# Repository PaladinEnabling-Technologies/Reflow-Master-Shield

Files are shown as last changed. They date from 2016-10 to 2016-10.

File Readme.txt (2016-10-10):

Readme
:
*******

1. Congratulations if you've purchased an Paladin Enabling Technologies solder reflow shield / controller, 
   if you decide to make it yourself, goodluck.

2. Before we can start reflowing your boards you will have to first load the EEPROM Population sketch onto the board,
   this is to move the default values into the EEPROM and to save you some time programming it in by hand.

3. If your not using an Arduino UNO but an Arduino Mega, then you will have to copy a replacement config file
   into your openGLCD library folder so that the shield will work.

4. The file is found in the "Master Config File - Same Pinout for all boards" folder and must be copied to the
   "C:\Program Files\Arduino\libraries\openGLCD" folder if this is your installation path of your Arduino IDE.

5. You can replace this file with the original master config file found in the "Master Config File - Original"
   folder if your not going to use the shield anymore and would like to use the default pinout for the Arduino Mega,

6. Next we can load the main Solder Reflow Oven Coding Sketch onto your board. There are two versions available. One for
   the UNO and one for the MEGA. 

7. Please note that the default values are for the toaster oven that we have used,
   you might have to adjust it for the oven your using as well as for the solder paste.

8. Please note that when you're in a submenu, you can navigate through it by pressing the ENT button.
   You can't escape so you must navigate through the menu. (You will notice that the "ESC" will disappear if you need to 
   navigate through a submenu)

9. Please read through the additional documentation in the sketches.

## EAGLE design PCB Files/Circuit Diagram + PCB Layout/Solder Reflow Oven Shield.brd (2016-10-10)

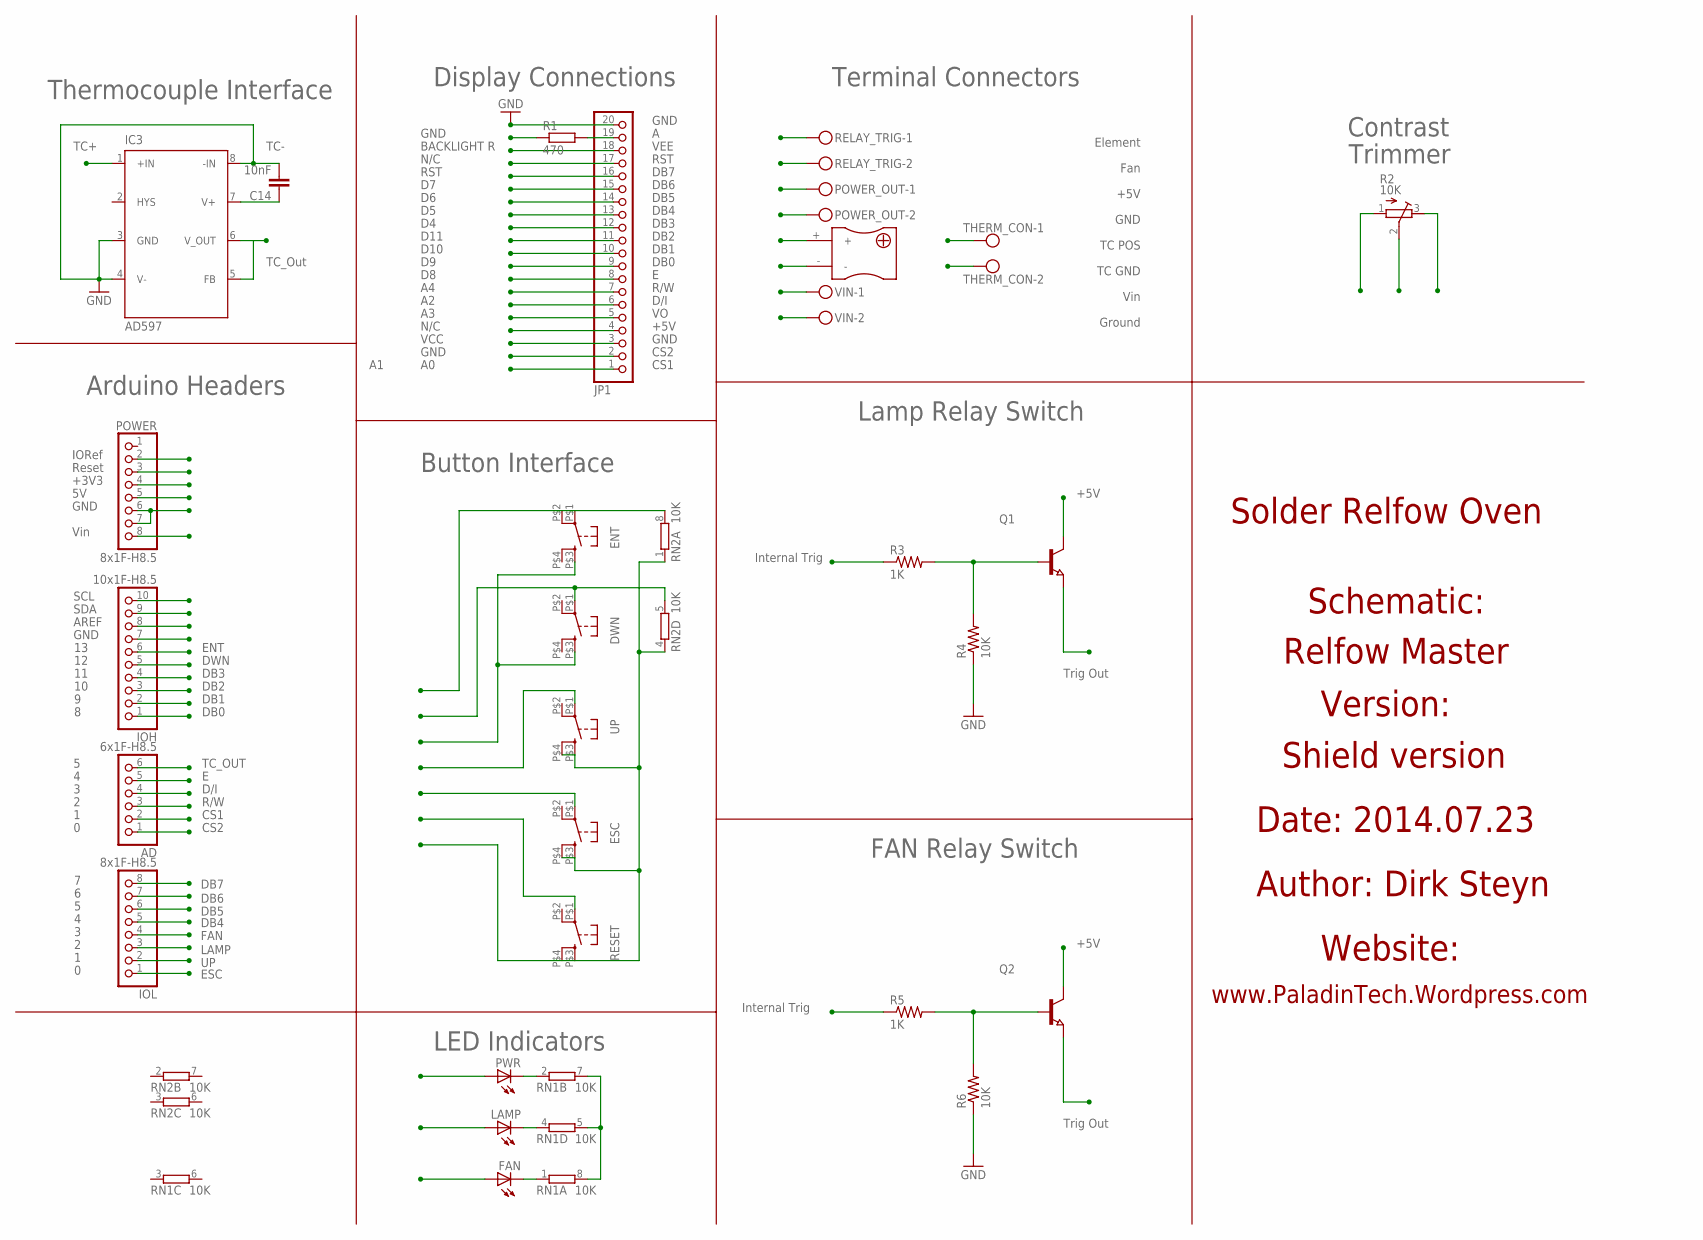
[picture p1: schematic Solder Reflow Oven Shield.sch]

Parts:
AD: 6x1F-H8.5; 1X06
C14: 10nF; C0603
DWN: MANTECH_TAC
ENT: MANTECH_TAC
ESC: MANTECH_TAC
FAN: LEDCHIP-LED0603; CHIP-LED0603
IC3: AD597; SO8
IOH: 10x1F-H8.5; 1X10
IOL: 8x1F-H8.5; 1X08
JP1: PINHD-1X20; 1X20
LAMP: LEDCHIP-LED0603; CHIP-LED0603
POWER: 8x1F-H8.5; 1X08
POWER_OUT: MKDSN1,5/2-5,08; 2XPCB_TER
PWR: LEDCHIP-LED0603; CHIP-LED0603
Q1, Q2: NPN-TRANSISTOR_SOT23; SOT23
R1: 470; R0603
R2: 10K; MURATA_PVZ3A
R3, R5: 1K; R0603
R4, R6: 10K; R0603
RELAY_TRIG: MKDSN1,5/2-5,08; 2XPCB_TER
RESET: MANTECH_TAC
RN1, RN2: 10K; EXB38V
THERM_CON: MKDSN1,5/2-5,08; 2XPCB_TER
U$1: THERMOCOUPLEPLUG_MINI; TC-MINI
UP: MANTECH_TAC
VIN: MKDSN1,5/2-5,08; 2XPCB_TER

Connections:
+3V3: POWER.4
+5V: C14.1, DWN.P$3 (3), ENT.P$3 (3), IC3.7 (V+), JP1.4, POWER.5, POWER_OUT.1, PWR.A, Q1.3 (C), Q2.3 (C), R1.1
A: JP1.19, R1.2
AREF: IOH.8
CS1: AD.2, JP1.1
CS2: AD.1, JP1.2
D/I: AD.4, JP1.6
DB0: IOH.1, JP1.9
DB1: IOH.2, JP1.10
DB2: IOH.3, JP1.11
DB3: IOH.4, JP1.12
DB4: IOL.5, JP1.13
DB5: IOL.6, JP1.14
DB6: IOL.7, JP1.15
DB7: IOL.8, JP1.16
DWN: DWN.P$1 (1), IOH.5, RN2.5 (2)
E: AD.5, JP1.8
ELEMENT_OUT: Q1.2 (E), RELAY_TRIG.1
ENT: ENT.P$1 (1), ENT.P$2 (2), IOH.6, RN2.8 (2)
ESC: ESC.P$1 (1), IOL.1
FAN: FAN.A, IOL.4, R5.1
FAN_OUT: Q2.2 (E), RELAY_TRIG.2
GND: C14.2, ESC.P$3 (3), ESC.P$4 (4), IC3.3 (GND), IC3.4 (V-), IC3.8 (-IN), IOH.7, JP1.3, JP1.20, POWER.6, POWER.7, POWER_OUT.2, R2.3, R4.1, R6.1, RESET.P$3 (3), RESET.P$4 (4), RN1.5 (2), RN1.7 (2), RN1.8 (2), RN2.1, RN2.4 (1), THERM_CON.2, U$1.-, UP.P$3 (3), UP.P$4 (4), VIN.2
IOREF: POWER.2
LAMP: IOL.3, LAMP.A, R3.1
unnamed: LAMP.C, RN1.4 (1)
unnamed: PWR.C, RN1.2 (1)
unnamed: FAN.C, RN1.1
unnamed: Q1.1 (B), R3.2, R4.2
unnamed: Q2.1 (B), R5.2, R6.2
R/W: AD.3, JP1.7
RST: JP1.17, POWER.3, RESET.P$1 (1)
SCL: IOH.9
SDA: IOH.10
TC+: IC3.1 (+IN), THERM_CON.1, U$1.+
TC_OUT: AD.6, IC3.5 (FB), IC3.6 (V_OUT)
UP: IOL.2, UP.P$1 (1)
VEE: JP1.18, R2.1
VIN: POWER.8, VIN.1
VO: JP1.5, R2.2

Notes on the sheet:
SDA
SCL
AREF
Fan
GND
Ground
Vin
TC POS
TC GND
Reset
+3V3
Element
+5V
ESC
LAMP
FAN
DB4
DB5
DB6
DB7
ENT
DWN
DB3
DB2
DB1
DB0
TC_OUT
D/I
R/W
CS2
CS1
IORef
Display Connections
Thermocouple Interface
LED Indicators
Arduino Headers
Button Interface
FAN Relay Switch
Lamp Relay Switch
Contrast

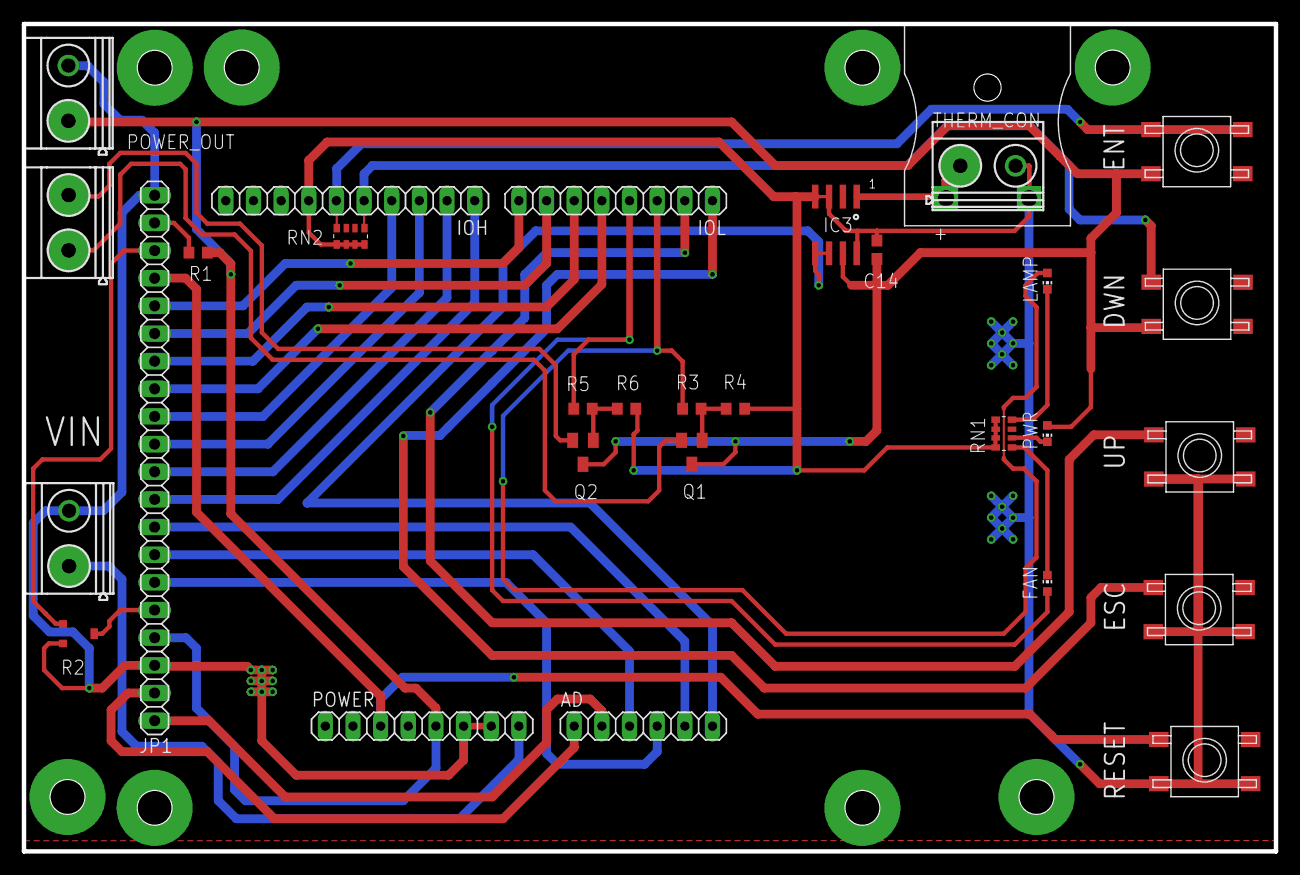
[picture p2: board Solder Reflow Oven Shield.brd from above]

Board: 2 copper layers, 115.0 x 76.0 mm, 30 parts (0 on the bottom side), 35 nets.

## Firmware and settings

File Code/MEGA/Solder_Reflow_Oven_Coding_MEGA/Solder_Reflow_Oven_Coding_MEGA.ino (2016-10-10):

  /******************************************************************************************************************************************************************************
  
  Title:    Reflow Master Shield - Solder Reflow Oven Controller
  Version:  1.1
  Date:     2014.09.27
  Company:  Paladin Enabling Techologies
  Author:   Dirk Steyn
  Website:  www.PaladinTech.Wordpress.com
  
  Notes
  ******
  This firmware was written for an open source solder reflow oven controller to match the commercial offerings at a much better offering. The default programmed curve is for lead-free 
  solder paste. The curve is completely configurable to the user's preference. This includes the stage temperatures as well as the holding times. The controller works as follows. A PREH 
  temperaure is the first setpoint. Once the setpoint is reached a countdown timer is started and the temperature is held at the first setpoint. Once the countdown timer reaches 0 min and 
  0 sec the next stage's setpoint is implemented. The next stage being the SOAK stage which is 200 Degrees Celcius. So the temperature is increased until the SOAK setpoint is reached. At 
  this stage the SOAK stage countdown timer is started. Once again when it reaches 0 min and 0 sec, the next stage is implemented. This being the RFLW stage. The setpoint is set to the 
  RFLW temperature being 245 Deg Celcius. Once the setpoint is reached the RFLW countdown timer starts until it reaches 0 min and 0 sec. Once this is reached the PID controller switches
  off and the oven cools down naturaly.
  
  There is also a KEEP setpoint and a COOL setpoint. The KEEP setpoint is set for 180 Degrees Celcius while the COOL setpoint is set for 150 Degrees Celcius. The controller has a build-in 
  secondary relay control circuit to operate an extraction fan to quickly cool from the KEEP setpoint to the COOL setpoint. Once the KEEP setpoint is reached the fan relay circuit switches 
  and activates the relay to activate the extraction fan to extract the hot fumes quickly so that the temperature drops to the COOL temperature setpoint. At this stage it will switch off 
  again to naturally cool down. You have the choice to either use the fan relay switching circuit by activating it or to not use it by leaving it deactivated.
  
  Once the temperature drops below 50 Degrees Celcius or the the final count up timer reaches 30 minutes, the program will exit to the main menu. The unit also has a function to store all 
  the program variables to the EEPROM so that if you power down the unit and power it back up you don't lose your program variables. This allows the unit to be a standalone unit without the 
  need to use a computer.
  
  
  Temperature (Degree Celcius)
  
  245-     |                                                             * * *
           |                                                           * |     | *
           |                                                         *   |     |   *
           |                                                       *     |     |    *
  200-     |                                           * * * * * *       |     |      *
           |                                         * |         |       |     |        *
           |                                       *   |         |       |     |        |*
           |                                     *     |         |       |     |        | *
  150-     |               * * * * * * * * * * *       |         |       |     |        |  *
           |             * |                   |       |         |       |     |        |    *
           |           *   |                   |       |         |       |     |        |      *
           |         *     |                   |       |         |       |     |        |      |  *
           |       *       |                   |       |         |       |     |        |      |     *
           |     *         |                   |       |         |       |     |        |      |         *
           |   *           |                   |       |         |       |     |        |      |              *
  Ambient- | *             |                   |       |         |       |     |        |      |                   *
           |               |                   |       |         |       |     |        |      |
           |       1       |         2         |   3   |    4    |   5   |  6  |   7    |  8   |           9
   0       |_ _ _ _ _ _ _ _|_ _ _ _ _ _ _ _ _ _|_ _ _ _|_ _ _ _ _| _ _ _ |_ _ _|_ _ _ _ | _ _ _|_ _ _ _ _ _ _ _ _ _ _
  
                                                                 Time (Seconds)
  
  
  Brief Operation:
  *****************
  
  1.    The temperature ramps up to the specified PREH temperature.
  2.    Once the PREH temperature is reached a holding timer starts to count down to keep the temperature constant.
  3.    When the count down timer reaches 0 the SOAK setpoint is implemented and the temperature ramps up to the desired setpoint.
  4.    When the setpoint is reached the appropriate count down timer is initiated.
  5.    Once the timer reaches 0 the RFLW setpoint is implemented and the temperature ramps up towards the setpoint.
  6.    Once the sepotint is reached the appropriate count down timer is initiated.
  7.    Once the count down timer reaches 0 a count up timer is initiated and the PID controller is switched off.
  8.    Once the KEEP setpoint is reached an extractor fan is activated (optional).
  9.    When the COOL setpoint is reached the extractor fan is de-activated and the status changes to DONE.

  
  Hysteresis Function:
  *********************
  There is a built in hysteresis function for each ramping stage. It can be used if the PID controller is struggling to reach the specific ramp setpoint. What it does is, it adds the 
  hysteresis temp to the setpoint during the ramp stage only. So that the PID controller will be fully on a bit longer than it normally would, ensuring that you reach your setpoint quicker 
  and that the PID controller doesn't linger just beneath the setpoint. Once the setpoint is reached and the count down timer is initiated the hysteresis value is discarded and the setpoint 
  is set back to the orginal setpoint. The hysteresis for each ramp stage is limited to 30 Degrees Celcius. Setting it too high might result in overshooting your setpoint by a bit.
  
  Libraries:
  ***********
  The firmware came into being from other design references but at the heart of the controller lies Brett Beauregard's (www.brettbeauregard.com) PID library as well as the openGLCD library.
  So to get the code to work you will have to download the following libraries from here:
  
  Arduino PID Library:
  >> https://github.com/br3ttb/Arduino-PID-Library
  
  openGLCD Library:
  >> https://bitbucket.org/bperrybap/openglcd/wiki/Home
  
  As far as open source goes, this firmware is opensource as well as the hardware, BUT, the reproducing of the hardware for commerical use is limited to
  Paladin Enabling Technologies and whoever Paladin Enabling Technologies might endorse with an production license.
  
  
  DISCLAIMER:
  ***********
  Working with high voltage is DANGEROUS. Make sure that you know what you are doing and that you have the proper knowledge before hand.  Your use of any
  information or materials on this reflow oven controller is entirely at your own risk for which Paladin Enabling Technologies will not be held liable for.
  
  Licences:
  *********
  The hardware and firmware designs of this solder reflow oven controller are released under the Creative Commons Share Alike v3.0 license
  
  http://creativecommons.org/licenses/by-sa/3.0/
  
  You are free to take this code, use it and modify it. All we ask is attribution including the supporting libraries used in this
  firmware. Reproducing the hardware commercially however is prohibited.
  
  ******************************************************************************************************************************************************************************/
  
  #include <PID_v1.h>
  
  #include <openGLCD.h>
  #include <include/openGLCD_GLCDv3.h>       // Header to provide GLCDv3 compatibility
  
  #include <fonts/allFonts.h>                // Include the Fonts
  #include <avr/eeprom.h>                    // Includes the EEPROM library to save variables to EEPROM
  
  #define RelayPin 2
  
  unsigned long StartofTimer_Seconds = 0;
  unsigned long StartofTimer_Graphing_Interval = 0;
  
  //******************************************************************************************************************************************************************************
  //**************************************                        User programmable Setable Values                       *********************************************************
  //******************************************************************************************************************************************************************************
  
  byte Reflow_Program_Cutout_Time = 30;        //  The time that the process must keep on displaying before exiting to the main menu after reflow process is completed.
  //  (Note temperature takes a while to cool down to below 50 Deg C, about 30 min with the oven I'm using. (50 Deg C = Own madeup safe temp).
  
  byte Reflow_Program_Cutout_Temp = 50;        //  The temp that must be reached once the reflow process have been completed before exiting to the main menu.
  //  (Note that the program will quit to the main menu either when the temp. drops below the cutout temp value or when the timer goes above the cutout time value. Timer value in minutes.)
  
  byte Temp_Offset = 3;                        //  Offset to compensate if the PID controller is not keeping the temperature on target. Can be a positive or a negative value. The value
  //  shouldn't exceed 5 Deg C.
  
  //******************************************************************************************************************************************************************************
  //**************************************                        Declaring further global variables                     *********************************************************
  //******************************************************************************************************************************************************************************
  
  int Stored_Values [12];    //  Array to store variables into the EEPROM
  
  //*********************************************************************************************************************************************************
  
  char* String_Lookup_Table_Array[] =     // String array with 21 elements.
  {
    "MENU:",                              // String 0
    "ESC",                                // String 1
    "ENT",                                // String 2
    "PREH",                               // String 3
    "SOAK",                               // String 4
    "RFLW",                               // String 5
    "KEEP",                               // String 6
    "COOL",                               // String 7
    "DONE",                               // String 8
    "HYSTERESIS",                         // String 9
    "EDIT",                               // String 10
    "VIEW",                               // String 11
    "RUN",                                // String 12
    "STORE",                              // String 13
    "PROGRAM",                            // String 14
    "PROFILE",                            // String 15
    "FAN STATUS",                         // String 16
    "OFF",                                // String 17
    " ON",                                // String 18
    "STORING VARIABLES",                  // String 19
    "TO EEPROM",                          // String 20
    "STORE",                              // String 21
    "VARIABLES"                           // String 22
  };
  
  //*********************************************************************************************************************************************************
  
  const int numReadings = 10;     // Averaging Variable
  
  int readings[numReadings];      // the readings from the analog input
  int index = 0;                  // the index of the current reading
  int total = 0;                  // the running total
  int Raw_Value_Avg = 0;          // the average
  int Raw_Value = 0;
  
  //******************************************************************************************************************************************************************************
  //**************************************                           Declaring PID Controller P                          *********************************************************
  //******************************************************************************************************************************************************************************
  
  // ***** PID PARAMETERS *****
  // ***** PRE-HEAT STAGE *****
  #define PID_KP_PREH 100
  #define PID_KI_PREH 0.025
  #define PID_KD_PREH 20
  // ***** SOAKING STAGE *****
  #define PID_KP_HEAT 300
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
  void loop()
  {
  
    Read_Buttons();
    Draw_Menu_Blocks();
  
    if ( Button_States_Selectors_and_Detectors[11]  == 1)
    {
      GLCD.SelectFont(System5x7, WHITE);
      GLCD.CursorToXY(50, 3);
      GLCD.print(String_Lookup_Table_Array[0]);
    }
  
    Test_UP_DOWN_Counter();
    Test_ENT_ESC_Counter_Value();
  
    if ( Button_States_Selectors_and_Detectors[11]  <= 1 )
    {
      Button_States_Selectors_and_Detectors[11] = 1;
    }
  
    if ( Button_States_Selectors_and_Detectors[11]  >= 3 )
    {
      Button_States_Selectors_and_Detectors[11] = 1;
    }
  
    if (Button_States_Selectors_and_Detectors[10] < 1 )
    {
      Button_States_Selectors_and_Detectors[10] = 4;
    }
  
    if ( Button_States_Selectors_and_Detectors[10] > 4 )
    {
      Button_States_Selectors_and_Detectors[10] = 1;
    }
  
    Main_Menu_Case_Switch();
  
    //****************************************************************************************************************************************************************************
    //**************************************                         Entering Submenu Edit Paramaters                      *******************************************************
    //****************************************************************************************************************************************************************************
  
    if ( Button_States_Selectors_and_Detectors[11]  == 2 && Button_States_Selectors_and_Detectors[10] == 1 )
    {
      GLCD.ClearScreen();
      Button_States_Selectors_and_Detectors[10] = 1;
      Button_States_Selectors_and_Detectors[8] = 1;
  
      Draw_Submenu_Lines();
  
      while ( Button_States_Selectors_and_Detectors[11]  == 2 )
      {
        Main_Menu_Case_Switch();
  
        Read_Buttons();
  
        GLCD.DrawLine( 31, 52,  31, 62);    // Lines to draw four blocks at the bottom.
        GLCD.DrawLine( 63, 52,  63, 62);
        GLCD.DrawLine( 94, 52,  94, 62);
  
        Test_UP_DOWN_Counter();
        Test_ENT_ESC_Counter_Value();
  
        Not_Highlighted_Up_Button();
        Not_Highlighted_Down_Button();
  
        if (Button_States_Selectors_and_Detectors[10] < 1 )
        {
          Button_States_Selectors_and_Detectors[10] = 3;
        }
        if (Button_States_Selectors_and_Detectors[10] > 3 )
        {
          Button_States_Selectors_and_Detectors[10] = 1;
        }
  
        SubMenu_Edit_Program();
        SubMenu_Edit_Hysteresis();
        SubMenu_Fan_Status();
  
      }
  
      GLCD.ClearScreen();
      Draw_Menu_Blocks();
      Button_States_Selectors_and_Detectors[10] = 1;
  
    }
  
    //****************************************************************************************************************************************************************************
    //**************************************                         Entering Submenu View Program                        ********************************************************
    //****************************************************************************************************************************************************************************
  
    if ( Button_States_Selectors_and_Detectors[11]  == 2 && Button_States_Selectors_and_Detectors[10] == 2 )
    {
      Button_States_Selectors_and_Detectors[10] = 1;
      GLCD.ClearScreen();
  
  
      while ( Button_States_Selectors_and_Detectors[11]  == 2 )
      {
        Read_Buttons();
  
        GLCD.DrawLine( 31, 52,  31, 62);    // Lines to draw four blocks at the bottom.
        GLCD.DrawLine( 63, 52,  63, 62);
        GLCD.DrawLine( 94, 52,  94, 62);
  
        Test_UP_DOWN_Counter();
        Test_ENT_ESC_Counter_Value();
  
        if (Button_States_Selectors_and_Detectors[10] < 1 )
        {
          Button_States_Selectors_and_Detectors[10] = 4;
        }
        if (Button_States_Selectors_and_Detectors[10] > 4 )
        {
          Button_States_Selectors_and_Detectors[10] = 1;
        }
  
        View_Program();
      }
      GLCD.ClearScreen();
      Draw_Menu_Blocks();
    }
  
    //****************************************************************************************************************************************************************************
    //**************************************                              RUNNING CYCLE SCREEN                             *******************************************************
    //****************************************************************************************************************************************************************************
  
    if ( Button_States_Selectors_and_Detectors[11]  == 2 && Button_States_Selectors_and_Detectors[10] == 3 )
    {
      GLCD.ClearScreen();
  
      while ( Button_States_Selectors_and_Detectors[11]  == 2 )
      {
        Read_Buttons();
  
        RunningCycleScreen();
  
        if ( Button_States_Selectors_and_Detectors[0] == LOW )
        {
          Button_States_Selectors_and_Detectors[11]--;
          GLCD.ClearScreen();
  
          if ( Button_States_Selectors_and_Detectors[11] < 0 )
          {
            Button_States_Selectors_and_Detectors[11] = 0;
          }
        }
  
        Button_States_Selectors_and_Detectors[0]   = 0;
        Button_States_Selectors_and_Detectors[10]   = 1;
  
      }
      GLCD.ClearScreen();
      Draw_Menu_Blocks();
    }
  
    //****************************************************************************************************************************************************************************
    //**************************************                      STORING VARIABLE VARIABLES TO EEPROM                     *******************************************************
    //****************************************************************************************************************************************************************************
  
    if ( Button_States_Selectors_and_Detectors[11]  == 2 && Button_States_Selectors_and_Detectors[10] == 4 )
    {
      GLCD.ClearScreen();
  
      Convert_Minutes_to_Seconds();                                                        // Converts minutes into seconds for storage
  
      Store_Variables_into_Storage_Array_Elements();                                       // Store variables to storage array
  
      eeprom_write_block((const void*)&Stored_Values, (void*)0, sizeof(Stored_Values));    // Store storage array values into EEPROM
  
      Convert_Seconds_to_Minutes();                                                        // Converts seconds back to minutes for usage in the program
  
      GLCD.SelectFont(System5x7, BLACK);
  
      GLCD.CursorToXY(2, 15);
  
      GLCD.CursorToXY(14, 25);
      GLCD.print(String_Lookup_Table_Array[19]);
      GLCD.CursorToXY(38, 35);
      GLCD.print(String_Lookup_Table_Array[20]);
  
      GLCD.DrawRect( 10, 21, 108, 23, BLACK);
      GLCD.DrawRect(  8, 19, 112, 27, BLACK);
  
      delay(2000);
  
      Button_States_Selectors_and_Detectors[11]     = 1;
      Button_States_Selectors_and_Detectors[10]     = 1;
  
      GLCD.ClearScreen();
      Draw_Menu_Blocks();
    }
  }
  
  //****************************************************************************************************************************************************************************
  //**************************************                        Draw Submenu Lines and text    *******************************************************************************
  //****************************************************************************************************************************************************************************
  
  void Draw_Submenu_Lines()
  {
    Draw_Menu_Blocks();
    GLCD.SelectFont(System5x7, WHITE);
    GLCD.DrawLine(  29, 2, 106, 2);                  // Line above Edit Program
    GLCD.FillRect(  26, 2,   2,  8, BLACK);
    GLCD.CursorToXY(29, 3 );
    GLCD.print(String_Lookup_Table_Array[10]);
    GLCD.print(" ");
    GLCD.print(String_Lookup_Table_Array[14]);
    GLCD.print(":");
  }
  
  void Hysteresis_Space_Calculator ( int Hysteresis_Variable )
  {
    if ( Hysteresis_Variable < 10 )
    {
      GLCD.print(" ");
      GLCD.print(Hysteresis_Variable);
    }
  
    else
    {
      GLCD.print(Hysteresis_Variable);
    }
  }
  
  void Hysteresis_Limiter()
  {
    if ( Button_States_Selectors_and_Detectors[9] <= 0 )
    {
      Button_States_Selectors_and_Detectors[9] = 0;
    }
  
    if ( Button_States_Selectors_and_Detectors[9] >= 30 )
    {
      Button_States_Selectors_and_Detectors[9] = 30;
    }
  }
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

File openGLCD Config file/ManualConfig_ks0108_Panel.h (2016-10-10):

/*

 * ManualConfig_ks0108.h - User specific configuration for openGLCD library

 *

 * Use this file to set io pins and LCD panel parameters

 * This version is for a standard/generic ks0108 display

 *

 */



#ifndef GLCD_PANEL_CONFIG_H

#define GLCD_PANEL_CONFIG_H



/*

 * define name for panel configuration

 */



#define glcd_ConfigName "ks0108-Manual"





/*********************************************************/

/*  Configuration for LCD panel specific configuration   */

/*********************************************************/



#define DISPLAY_WIDTH 128

#define DISPLAY_HEIGHT 64




// panel controller chips

#define CHIP_WIDTH     64  // pixels per chip

#define CHIP_HEIGHT    64  // pixels per chip




/*********************************************************/

/*  Configuration for assigning LCD bits to Arduino Pins */

/*********************************************************/




/*
 * Pins can be assigned using Arduino pin numbers 0-n

 * Pins on AVR devices can also be assigned using PIN_Pb

 *   where P is port A-L and b is bit 0-7

 *   Example: port D pin 3 is PIN_D3

 *

 */





/* Data pin definitions
 */



#define glcdPinData0        8

#define glcdPinData1        9

#define glcdPinData2        10

#define glcdPinData3        11

#define glcdPinData4        4

#define glcdPinData5        5

#define glcdPinData6        6

#define glcdPinData7        7




/* Arduino pins used for control

 * default assignment uses the first five analog pins

 */


#define glcdPinCSEL1        A0  //14 - Original value

#define glcdPinCSEL2        A1  //15 - Original value



/*********************************************************/

/*    Defining additional chip selects if required       */

/*********************************************************/

// uncomment the following if more than two chip select pins are needed


//#define glcdPinCSEL3        3   // third chip select line on pin 3 if needed


//#define glcdPinCSEL4        2   // fourth chip select if needed






/*********************************************************/

/*         Defining other control pins needed            */

/*********************************************************/


#define glcdPinRW            A2 //16 - Original value

#define glcdPinDI            A3 //17 - Original value
#define glcdPinEN            A4 //18 - Original value



// Reset - uncomment the next line if glcd module reset is connected to an output pin

//#define glcdPinRES           19 // optional s/w Reset control



// backlight control pin

//#define glcdPinBL	     XX // optional backlight control pin controls BL circuit




/*

 * the following is the calculation of the number of chips - do not change
 */


#define glcd_CHIP_COUNT (((DISPLAY_WIDTH + CHIP_WIDTH - 1)  / CHIP_WIDTH) * ((DISPLAY_HEIGHT + CHIP_HEIGHT -1) / CHIP_HEIGHT))




/*********************************************************/

/*             Chip Select Configuration                 */

/*********************************************************/



/*

 * Change the following define to match the number of Chip Select pins for this panel

 * Most panels use two pins for chip select,

 * but check your datasheet to see if a different number is required

 */


#define NBR_CHIP_SELECT_PINS   2 // the number of chip select pins required for this panel



/*

 * The following conditional statements determine the relationship between the chip select

 * pins and the physical chips.

 * If the chips are displayed in the wrong order, you can swap the glcd_CHIPx defines 

 */ 


/* 

 * Defines for Panels using two Chip Select pins

 */  


#if  NBR_CHIP_SELECT_PINS == 2



/*

 * Two Chip panels using two select pins (the most common panel type)

 */


#if glcd_CHIP_COUNT == 2

#define glcd_CHIP0 glcdPinCSEL1,HIGH,   glcdPinCSEL2,LOW

#define glcd_CHIP1 glcdPinCSEL1,LOW,    glcdPinCSEL2,HIGH    




/*

 * Three Chip panel using two select pins

 */


#elif  glcd_CHIP_COUNT == 3 


#define glcd_CHIP0  glcdPinCSEL1,LOW,  glcdPinCSEL2,LOW

#define glcd_CHIP1  glcdPinCSEL1,LOW,  glcdPinCSEL2,HIGH

#define glcd_CHIP2  glcdPinCSEL1,HIGH, glcdPinCSEL2,LOW



/*

 * Four Chip panel using two select pins

 */


#elif  glcd_CHIP_COUNT == 4 

#define glcd_CHIP0  glcdPinCSEL1,LOW,  glcdPinCSEL2,LOW

#define glcd_CHIP1  glcdPinCSEL1,HIGH, glcdPinCSEL2,LOW

#define glcd_CHIP2  glcdPinCSEL1,HIGH, glcdPinCSEL2,HIGH    

#define glcd_CHIP3  glcdPinCSEL1,LOW,  glcdPinCSEL2,HIGH    

#endif



/*

 * Defines for Two Chip panels using one Chip Select pin 

 */


#elif  (NBR_CHIP_SELECT_PINS == 1 && glcd_CHIP_COUNT == 2)  

#define glcd_CHIP0  glcdPinCSEL1,LOW

#define glcd_CHIP1  glcdPinCSEL1,HIGH    



/*

 * Defines for Three Chip panels using three select pins

 */


#elif (NBR_CHIP_SELECT_PINS == 3 && glcd_CHIP_COUNT == 3)  

#define glcd_CHIP0  glcdPinCSEL1,HIGH, glcdPinCSEL2,LOW,  glcdPinCSEL3,LOW

#define glcd_CHIP1  glcdPinCSEL1,LOW,  glcdPinCSEL2,HIGH, glcdPinCSEL3,LOW
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

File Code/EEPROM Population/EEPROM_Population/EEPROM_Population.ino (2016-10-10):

    /******************************************************************************************************************************************************************************
   
    Title:    Solder Reflow Oven Controller
    Version:  1.1
    Date:     2014.09.27
    Company:  Paladin Enabling Techologies
    Author:   Dirk Steyn
    Website:  www.PaladinTech.Wordpress.com
    
    Notes
    ******
    This sketch is used to populate the EEPROM that the solder reflow oven will read upon startup. If this sketch is not run then all the values will be set to zero. By running
    this sketch the values are set to the default values and then you won't have to wait a while for the values to change by programming it via the buttons on of the reflow oven.
                        
    ******************************************************************************************************************************************************************************/  
    
    #include <avr/eeprom.h> 
  
    int led = 13;
   
    void setup() 
    {       
       pinMode(led, OUTPUT);          // initialize the digital pin as an output.
      
       int Stored_Values [12] =       //  Declaring default values to be stored into the EEPROM.
       { 
         150,                         //  PREH Default Temperature
         200,                         //  SOAK Default Temperature
         245,                         //  RFLW Default Temperature
         180,                         //  KEEP Default Temperature
         150,                         //  COOL Default Temperature
          30,                         //  PREH Keep Time
          20,                         //  SOAK Keep Time
          10,                         //  RFLW Keep Time
           0,                         //  PREH Hysteresis Value
          10,                         //  SOAK Hysteresis Value
          14,                         //  RFLW Hysteresis Value
           0                          //  Fan  Status - 1 = ON; 0 = OFF
       };        
       
       eeprom_write_block((const void*)&Stored_Values, (void*)0, sizeof(Stored_Values));    // Store storage array values into EEPROM
    }


    /* 
   
    By the time we reach the void loop, the values are already stored. We flicker LED13 to indicate that the 
    process is completed and that you can now load the main Solder Reflow Oven Controller Sketch onto the board.  
    
    */
        
    void loop()                       
    {
      digitalWrite(led, HIGH);   // turn the LED on (HIGH is the voltage level)
      delay(200);                // wait for a second
      digitalWrite(led, LOW);    // turn the LED off by making the voltage LOW
      delay(200);                // wait for a second
    }
    
    
    

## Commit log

2014-10-11 Reflow Master Shied
    Paladin Enabling Technologies
    Reflow Master Shield
    Circuit diagram, firmware, configuration files, variable explanation
    readme and general readme
    Enjoy
    [Paladin Enabling Technologies - Reflow Master Shield.sch]
2016-10-10 Circuit diagram, PCB design + Gerber Files
2016-10-10 Changed files to include everything
    Uploaded all the relevant files to be able to recreate this project by yourself. This includes the code, circuit diagram, PCB design, Gerber files etc.
    [Solder Reflow Oven Shield.brd, Solder Reflow Oven Shield.sch]
